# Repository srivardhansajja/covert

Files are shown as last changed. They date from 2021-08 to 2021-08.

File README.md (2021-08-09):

# Covert Communications Device

## UIUC ECE 445 Senior Design / Capstone Project

Won Best Engineered Project Award, and permanently listed in the [Hall of Fame](https://courses.engr.illinois.edu/ece445/hall-of-fame.asp) for Spring 2021

## Abstract

The primary purpose of this project is to provide a means for safe and effective communication in highly sensitive military and law-enforcement operations.

It is important for a two-way channel of communication to exist between the base and individuals in the field. Regular communication tools have output which can disrupt sensory awareness of the user thereby rendering them unsuitable for information transmission in these situations. A wearable device thatrelays messages that are only detectable by the user, and that will not affect their focus is the purpose of this project.

The final output of this project is a small device that can be installed on the human body in a convenient location, such as the upper arm or the outer thigh. The user should be able to access the device using their hand. The device will transmit information to the user through the cadence of haptic feedback (vibration patterns). The user will also be able to transmit information to all other devices in near real-time using a button on the device (pressing the button with whatever cadence is required, e.g. long-short-short). Team selected codes can be established to effectively transmit complex information or instructions.

## Prototype

Prototypes

## Block Diagram

Block Diagram

## Documents
- [Project Report](https://courses.engr.illinois.edu/ece445/getfile.asp?id=19398)
- [Design Document](https://courses.engr.illinois.edu/ece445/getfile.asp?id=19192)
- [Proposal](https://courses.engr.illinois.edu/ece445/getfile.asp?id=18686)

## Software
- STM32 CubeIDE development, LoRa radio communications + crypto libraries

## Board
- Eagle schematic + board files 
- CAD casing layout
- Gerber files

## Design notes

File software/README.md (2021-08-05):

# Sources:
https://github.com/henriheimann/stm32-hal-rfm95

https://github.com/sandeepmistry/arduino-LoRa

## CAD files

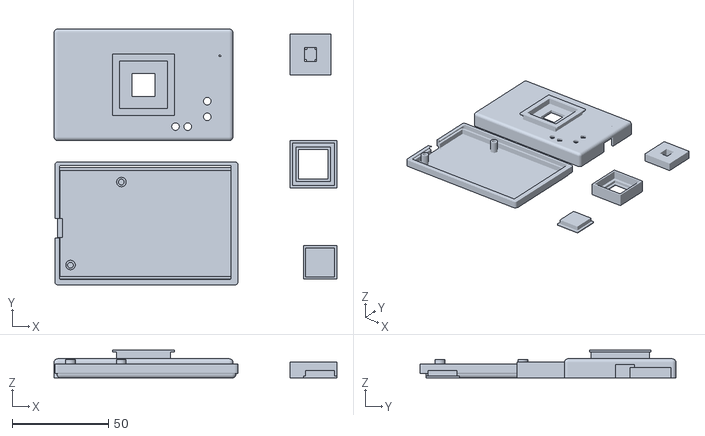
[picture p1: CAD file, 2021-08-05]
board/tinker.obj
147.0 x 133.0 x 14.5

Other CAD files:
board/seniordesign.dwg

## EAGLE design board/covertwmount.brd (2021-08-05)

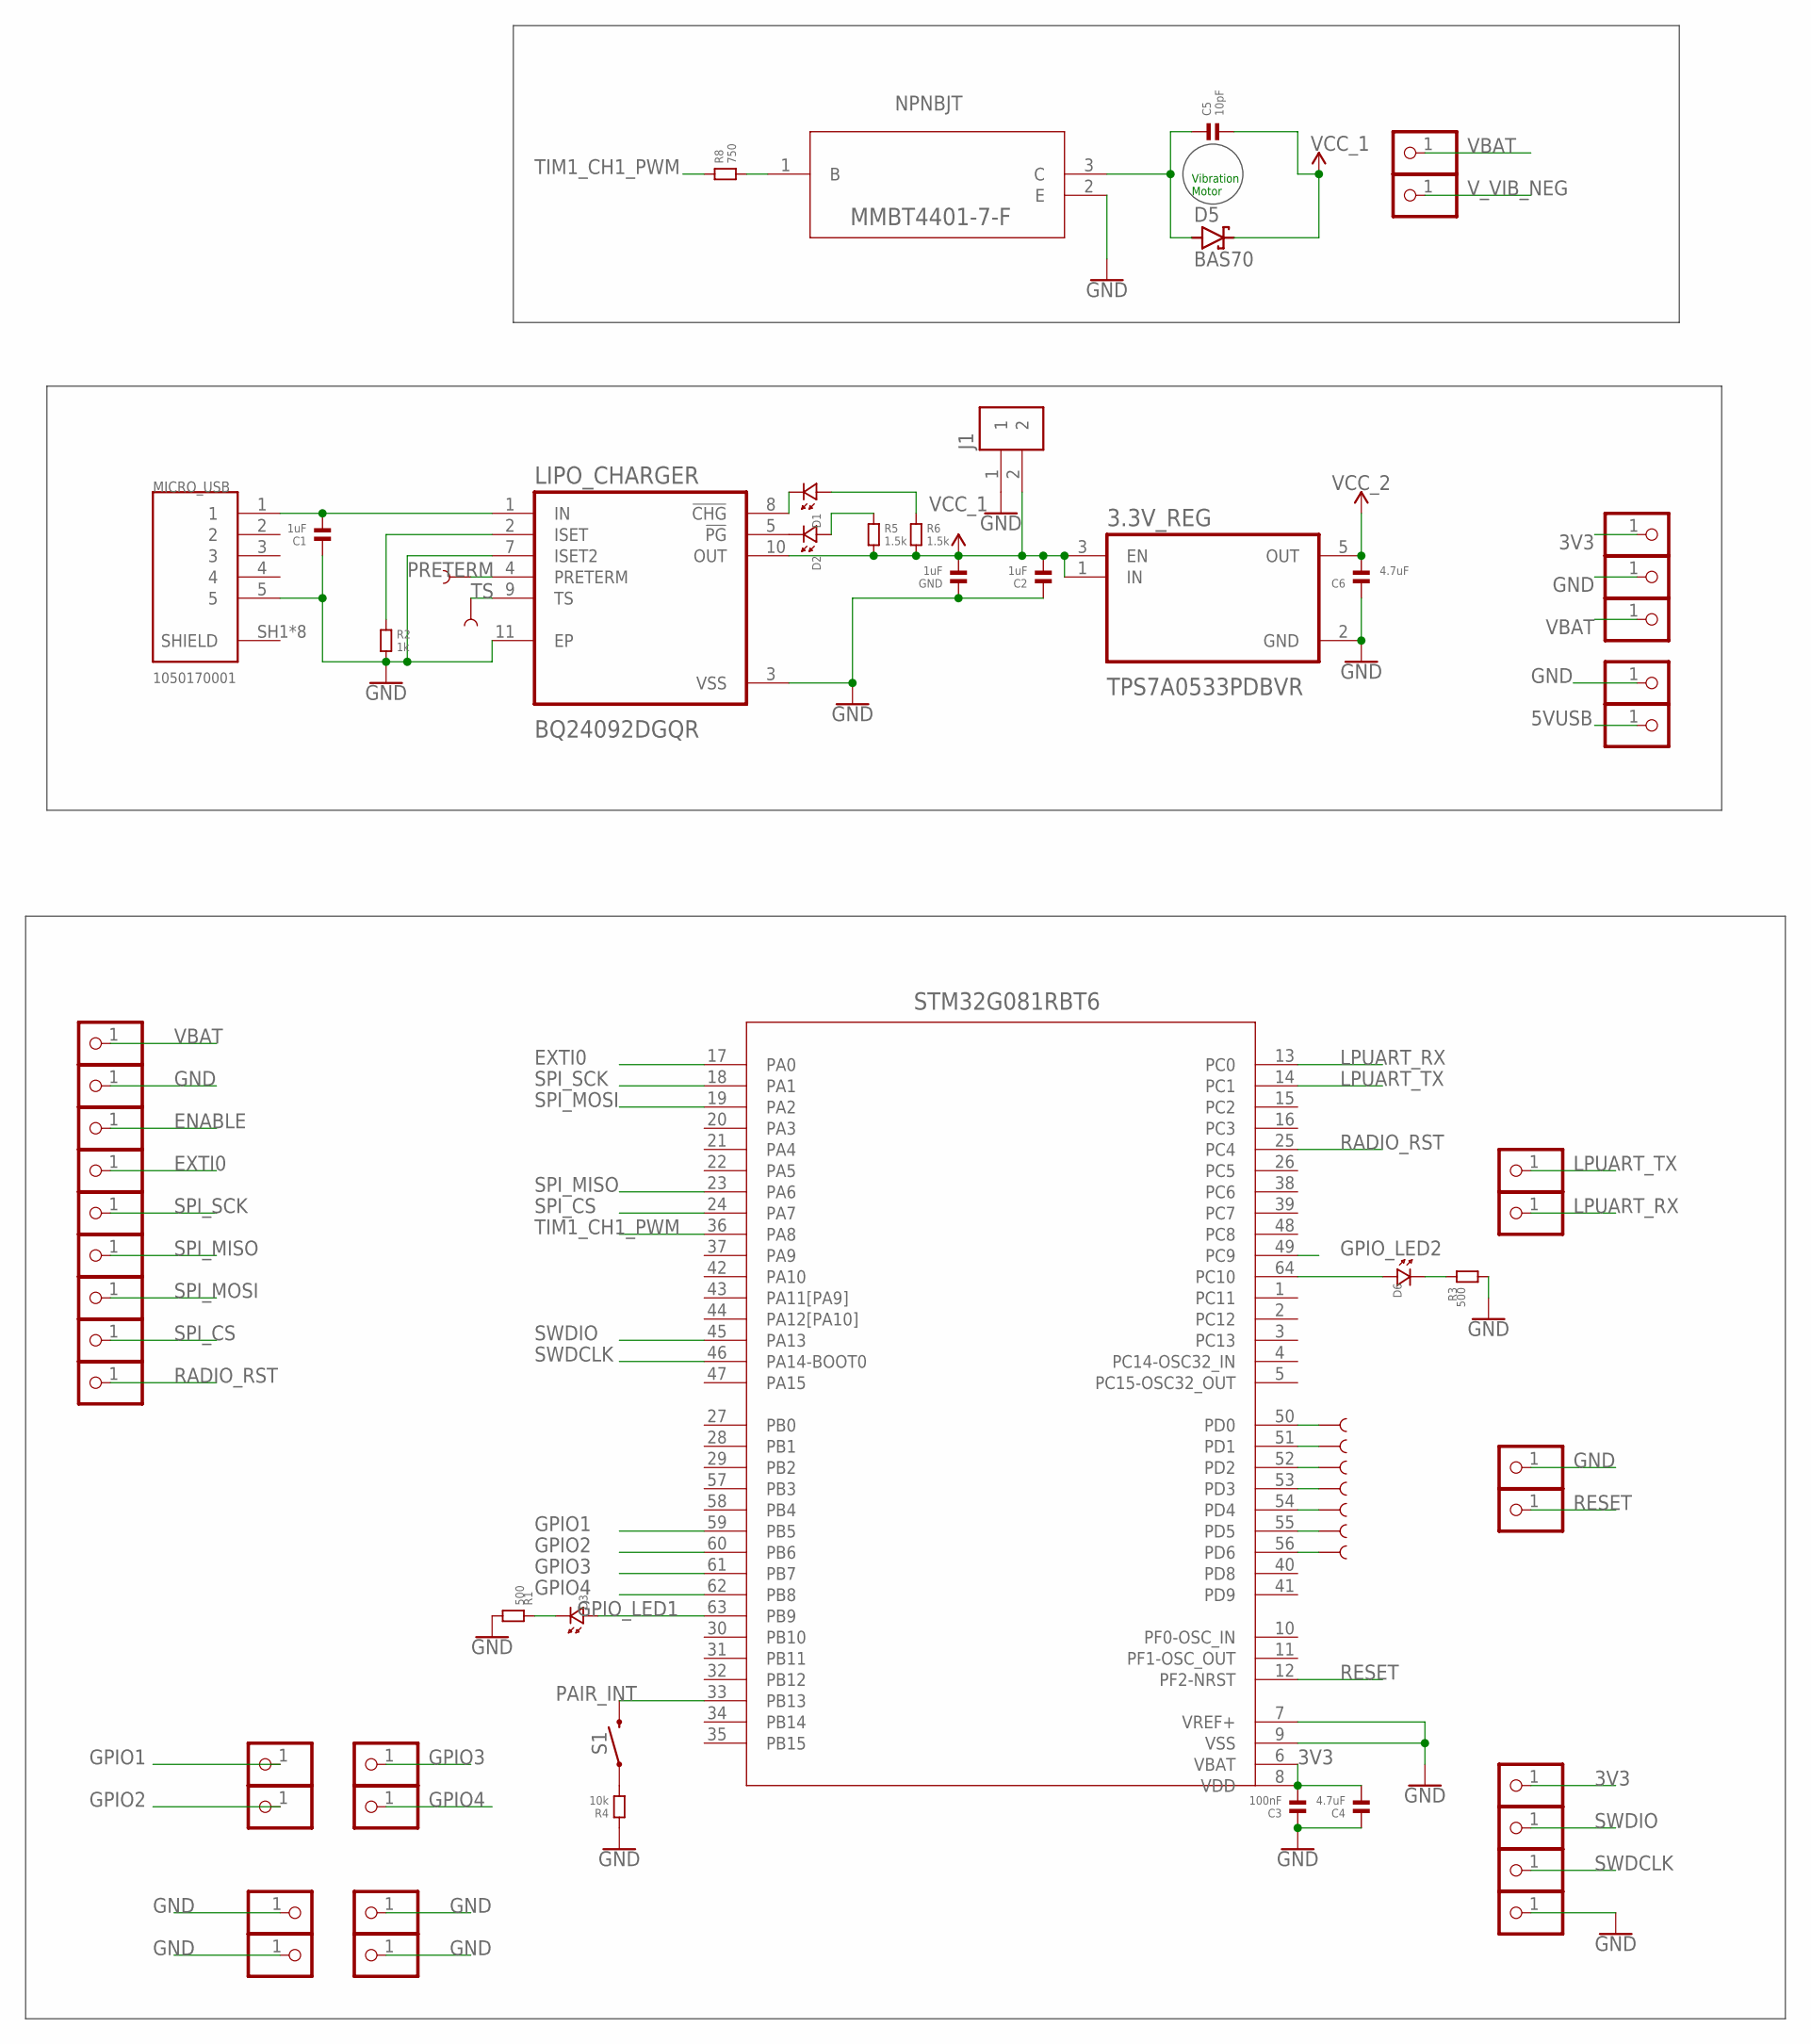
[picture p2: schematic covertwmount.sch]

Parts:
3.3V_REG: TPS7A0533PDBVR; SOT95P280X145-5N
C1, C2: 1uF; 0805
C3: 100nF; 0805
C4, C6: 4.7uF; 0805
C5: 10pF; 0805
D1, D2, D3, D6: LED.0805; 0805.LED
D5: BAS70; SOT23
GND: 1uF; 0805
J1: B2B-PH-K-S(LF)(SN); JST_B2B-PH-K-S(LF)(SN)
JP1, JP2, JP3, JP4, JP5, JP6, JP7, JP8, JP9, JP10, JP11, JP12, JP13, JP14, JP15, JP16, JP17, JP18, JP19, JP20, JP21, JP22, JP23, JP24, JP26, JP27, JP28, JP29, JP30, JP31, JP32, JP33: PINHD-1X1; 1X01
LIPO_CHARGER: BQ24092DGQR; IC_XTR111AIDGQR
MICRO_USB: 1050170001; MOLEX_1050170001
R1, R3: 500; 0805
R2: 1k; 0805
R4: 10k; 0805
R5, R6: 1.5k; 0805
R8: 750; 0805
S1: MOMENTARY-SWITCH-SPST-PTH-6.0MM; TACTILE_SWITCH_PTH_6.0MM
TP1, TP2, TP3, TP4, TP5, TP6, TP7, TP8, TP9: TEST-POINT2; PAD.02X.02
U1: STM32G081RBT6; LQFP-64
U2: MMBT4401-7-F; SOT-23_DIO

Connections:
3V3: 3.3V_REG.5 (OUT), C3.2, C4.2, C6.2, JP4.1, JP16.1, U1.6 (VBAT), U1.8 (VDD)
5VUSB: C1.2, JP30.1, LIPO_CHARGER.1 (IN), MICRO_USB.1
ENABLE: JP11.1
EXTI0: JP10.1, U1.17 (PA0)
GND: 3.3V_REG.2 (GND), C1.1, C2.1, C3.1, C4.1, C6.1, GND.1, J1.1, JP3.1, JP12.1, JP15.1, JP23.1, JP26.1, JP27.1, JP28.1, JP29.1, JP33.1, LIPO_CHARGER.3 (VSS), LIPO_CHARGER.7 (ISET2), LIPO_CHARGER.11 (EP), MICRO_USB.5, R1.1, R2.2, R3.1, R4.1, U1.7 (VREF+), U1.9 (VSS), U2.2 (E)
GPIO1: JP19.1, U1.59 (PB5)
GPIO2: JP20.1, U1.60 (PB6)
GPIO3: JP17.1, U1.61 (PB7)
GPIO4: JP18.1, U1.62 (PB8)
GPIO_LED1: D3.P$1 (1), U1.63 (PB9)
GPIO_LED2: D6.P$1 (1), U1.64 (PC10)
LPUART_RX: JP32.1, U1.13 (PC0)
LPUART_TX: JP31.1, U1.14 (PC1)
unnamed: LIPO_CHARGER.2 (ISET), R2.1
unnamed: D6.P$2 (2), R3.2
unnamed: D3.P$2 (2), R1.2
unnamed: D2.P$1 (1), R5.1
unnamed: D1.P$1 (1), R6.1
unnamed: D2.P$2 (2), LIPO_CHARGER.5 (!PG)
unnamed: R8.2, U2.1 (B)
unnamed: R4.2, S1.1
unnamed: D1.P$2 (2), LIPO_CHARGER.8 (!CHG)
PAIR_INT: S1.3 (2), U1.33 (PB13)
PD0: TP3.P$1, U1.50 (PD0)
PD1: TP4.P$1, U1.51 (PD1)
PD2: TP5.P$1, U1.52 (PD2)
PD3: TP6.P$1, U1.53 (PD3)
PD4: TP7.P$1, U1.54 (PD4)
PD5: TP8.P$1, U1.55 (PD5)
PD6: TP9.P$1, U1.56 (PD6)
PRETERM: LIPO_CHARGER.4 (PRETERM), TP2.P$1
RADIO_RST: JP5.1, U1.25 (PC4)
RESET: JP24.1, U1.12 (PF2-NRST)
SPI_CS: JP6.1, U1.24 (PA7)
SPI_MISO: JP8.1, U1.23 (PA6)
SPI_MOSI: JP7.1, U1.19 (PA2)
SPI_SCK: JP9.1, U1.18 (PA1)
SWDCLK: JP2.1, U1.46 (PA14-BOOT0)
SWDIO: JP1.1, U1.45 (PA13)
TIM1_CH1_PWM: R8.1, U1.36 (PA8)
TS: LIPO_CHARGER.9 (TS), TP1.P$1
VBAT: 3.3V_REG.1 (IN), 3.3V_REG.3 (EN), C2.2, C5.2, D5.3 (C), GND.2, J1.2, JP13.1, JP14.1, JP21.1, LIPO_CHARGER.10 (OUT), R5.2, R6.2
V_VIB_NEG: C5.1, D5.1 (A), JP22.1, U2.3 (C)

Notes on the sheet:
Vibration Motor

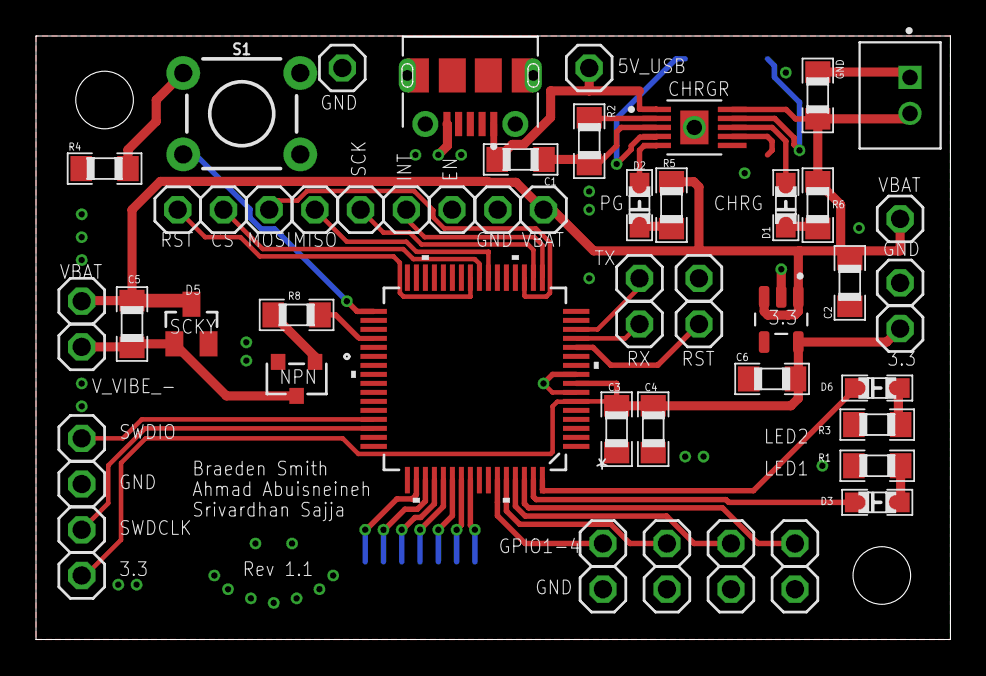
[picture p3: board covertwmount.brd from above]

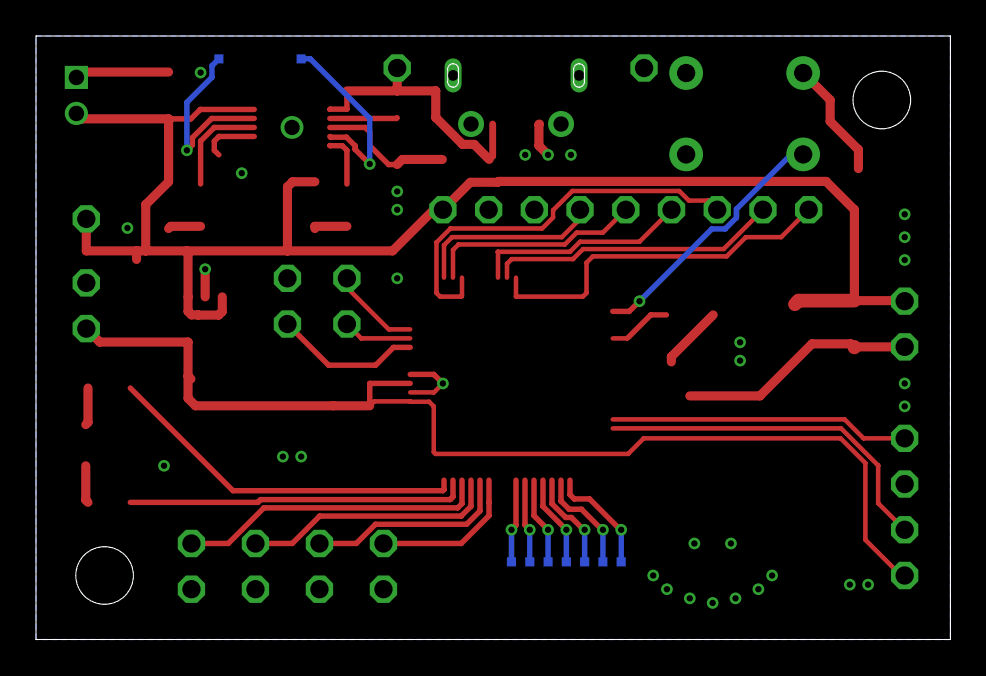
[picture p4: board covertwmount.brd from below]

Board: 2 copper layers, 50.8 x 33.5 mm, 67 parts (9 on the bottom side), 42 nets.

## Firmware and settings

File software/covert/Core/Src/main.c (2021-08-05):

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
/* Includes ------------------------------------------------------------------*/
#include "main.h"

/* USER CODE BEGIN Includes */
#include <string.h>
#include <assert.h>
#include "crypto.h"
#include "rfm95.h"

/* USER CODE END Includes */

/* USER CODE BEGIN PTD */
typedef struct {
	uint32_t privateKey[8];
	uint8_t publicKey[32];
	uint8_t otherPublicKey[32];
	uint8_t sharedSecret[32];
	volatile uint8_t gotOther;
	volatile uint8_t masterSent;
	volatile uint8_t pairing;
} AsymmetricKeys;

typedef struct {
	volatile uint8_t enabled;
	uint8_t count;
	uint64_t data;
} Record;

typedef struct __attribute__((__packed__)) {
	uint8_t preamble;
	uint8_t deviceID;
	uint32_t sequenceNumber;
	uint64_t data;
	uint16_t _placeholder;
} Packet;

typedef struct __attribute__((__packed__)) {
	uint8_t preamble;
	uint8_t data[32];
} PublicKeyPacket;

typedef struct __attribute__((__packed__)) {
	uint8_t preamble;
	uint8_t data[16];
} KeyExchangePacket;

/* USER CODE END PTD */

/* USER CODE BEGIN PD */

#define MASTER_DEVICE 	0
#define DEVICE_ID 		1
#define RESET 			0
#define NEW_SEQ			0

#define AESKeySize 128/8 //(8 * sizeof(uint32_t));
#define PUBLIC_EXCHANGE_PREAMBLE 0b01010101
#define AES_KEY_EXCHANGE_PREAMBLE 0b10101010
#define VIBE_PREAMBLE 0b11110000
#define DUTY_CYCLE_ON 10
/* USER CODE END PD */

CRYP_HandleTypeDef hcryp;
uint32_t pKeyAES[4] __ALIGN_END = { 0x00000000,
		0x00000000, 0x00000000, 0x00000000 };
__ALIGN_BEGIN static const uint32_t pInitVectAES[4] __ALIGN_END = { 0x5B841799,
		0xF2DBC132, 0x3961879F, 0x8B3F49C0 };

CRC_HandleTypeDef hcrc;

RNG_HandleTypeDef hrng;

SPI_HandleTypeDef hspi1;

TIM_HandleTypeDef htim1;
TIM_HandleTypeDef htim16;

/* USER CODE BEGIN PV */
FLASH_EraseInitTypeDef EraseInitStruct;
FLASH_EraseInitTypeDef EraseSeqStruct;

AsymmetricKeys aKeys;
Record playback;
Record recording;
Packet outgoing;
rfm95_handle_t radio;
uint32_t deviceSeqs[256] = { 0 };

/* USER CODE END PV */

void SystemClock_Config(void);
static void MX_GPIO_Init(void);
static void MX_AES_Init(void);
static void MX_RNG_Init(void);
static void MX_CRC_Init(void);
static void MX_TIM16_Init(void);
static void MX_TIM1_Init(void);
static void MX_SPI1_Init(void);
/* USER CODE BEGIN PFP */
static void readKeyFromFlash(uint32_t *ptr, FLASH_EraseInitTypeDef *erase);
static void writeKeyToFlash(uint64_t *ptr, FLASH_EraseInitTypeDef *erase);
static uint32_t readSeqFromFlash(FLASH_EraseInitTypeDef *erase);
static void writeSeqToFlash(uint32_t seq, FLASH_EraseInitTypeDef *erase);
static void readingCallback(uint8_t *buffer, uint8_t length);
/* USER CODE END PFP */

/**
 * @brief  The application entry point.
 * @retval int
 */
int main(void) {
	/* MCU Configuration--------------------------------------------------------*/

	/* Reset of all peripherals, Initializes the Flash interface and the Systick. */
	HAL_Init();

	/* Configure the system clock */
	SystemClock_Config();

	/* USER CODE BEGIN SysInit */
	uint8_t testing = sizeof(Packet);
	assert(
			sizeof(PublicKeyPacket) == 33 && sizeof(KeyExchangePacket) == 17
					&& sizeof(Packet) == 16);
	// Key writing to flash
	EraseInitStruct.Banks = FLASH_BANK_1;
	EraseInitStruct.TypeErase = FLASH_TYPEERASE_PAGES;
	EraseInitStruct.Page = (FLASH_PAGE_NB - 1);
	EraseInitStruct.NbPages = 1;

	// Sequence Number storing in flash
	EraseSeqStruct.Banks = FLASH_BANK_1;
	EraseSeqStruct.TypeErase = FLASH_TYPEERASE_PAGES;
	EraseSeqStruct.Page = (FLASH_PAGE_NB - 2);
	EraseSeqStruct.NbPages = 1;

	recording.enabled = 0;
	playback.enabled = 0;

	radio.spi_handle = &hspi1;

	radio.nss_port = RADIO_CS_GPIO_Port;
	radio.nss_pin = RADIO_CS_Pin;
	radio.nrst_port = RADIO_RESET_GPIO_Port;
	radio.nrst_pin = RADIO_RESET_Pin;
	radio.irq_port = RADIO_INT_GPIO_Port;
	radio.irq_pin = RADIO_INT_Pin;

	radio.txDone = true;
	radio.rxDoneCallback = readingCallback;

	aKeys.gotOther = 0;
	aKeys.pairing = 0;
	aKeys.masterSent = 0;
	aKeys.sharedSecret[0] = 0;

	outgoing.data = 0;

	/* USER CODE END SysInit */

	/* Initialize all configured peripherals */
	MX_GPIO_Init();
	MX_AES_Init();
	MX_RNG_Init();
	MX_CRC_Init();
	MX_TIM16_Init();
	MX_TIM1_Init();
	MX_SPI1_Init();
	/* USER CODE BEGIN 2 */

	HAL_Delay(100);
	if (!rfm95_init(&radio)) {
		HAL_GPIO_WritePin(LED2_GPIO_Port, LED2_Pin, GPIO_PIN_SET);
		HAL_GPIO_WritePin(LED1_GPIO_Port, LED1_Pin, GPIO_PIN_SET);

		while (1) {

		}
	}

	HAL_TIM_Base_Start_IT(&htim16);
	HAL_TIM_PWM_Start(&htim1, TIM_CHANNEL_1);

	readKeyFromFlash(pKeyAES, &EraseInitStruct);
	// We lost our random key or we want a reset?
	if (RESET || pKeyAES[0] == 0 || pKeyAES[0] == UINT32_MAX) {
		uint64_t tmp[2];
		for (int i = 0; i < 2; i++) {
			if (HAL_RNG_GenerateRandomNumber(&hrng, &tmp[i]) != HAL_OK)
				Error_Handler();
			tmp[i] <<= 32;
			if (HAL_RNG_GenerateRandomNumber(&hrng, &tmp[i]) != HAL_OK)
				Error_Handler();
		}
		writeKeyToFlash(tmp, &EraseInitStruct);
		readKeyFromFlash(pKeyAES, &EraseInitStruct);
	}
	MX_AES_Init();

	// Generate a random sequence number for packets -- assume 2000 is the most packets we'll ever send while devices haven't rebooted
	deviceSeqs[DEVICE_ID] = readSeqFromFlash(&EraseSeqStruct);
	if (NEW_SEQ || deviceSeqs[DEVICE_ID] >= ((UINT32_MAX) >> 1)
			|| deviceSeqs[DEVICE_ID] == 0) {
		uint32_t seq = 0;
		HAL_RNG_GenerateRandomNumber(&hrng, &seq);
		seq >>= 1;
		deviceSeqs[DEVICE_ID] = seq;
	}
	deviceSeqs[DEVICE_ID] += 2000;
	writeSeqToFlash(deviceSeqs[DEVICE_ID], &EraseSeqStruct);

	// Might as well generate a public key in advance
	for (int i = 0; i < 8; i++) {
		HAL_RNG_GenerateRandomNumber(&hrng, &aKeys.privateKey[i]);
	}
	C25519keyGen((uint8_t*) aKeys.privateKey, aKeys.publicKey);

	/* USER CODE END 2 */

	/* Infinite loop */
	/* USER CODE BEGIN WHILE */
	while (1) {
		if (aKeys.pairing && aKeys.pairing++ <= 5) {
			// send our public key in plaintext.
			PublicKeyPacket tmp;
			tmp.preamble = PUBLIC_EXCHANGE_PREAMBLE;
			memcpy(tmp.data, aKeys.publicKey, sizeof(tmp.data));
			transmitPackage(&tmp, sizeof(PublicKeyPacket));
			// randomize the delay here
			uint32_t randoffset = 0;
			HAL_RNG_GenerateRandomNumber(&hrng, &randoffset);

			HAL_Delay(1000 + (randoffset & 0x7ff));
			continue;
		} else {
			aKeys.pairing = 0;
		}

		if (aKeys.gotOther) {
			C25519keyExchange(aKeys.sharedSecret, (uint8_t*) aKeys.privateKey,
					aKeys.otherPublicKey);
//			rfm95_init(&radio);
			aKeys.gotOther = 0;
			aKeys.masterSent = 1;
		}

		if (aKeys.masterSent && aKeys.masterSent++ <= 10) {
			if (MASTER_DEVICE) {
				// Save the "master's secret key" in old pkeys
				uint32_t oldPkeys[4] = { 0 };
				memcpy(oldPkeys, pKeyAES, AESKeySize);
				// move the shared secret to the AES hardware for encryption
				memcpy(pKeyAES, aKeys.sharedSecret, AESKeySize);
				MX_AES_Init();
				// Create a packet & attack the "master's key"
				KeyExchangePacket tmp;
				tmp.preamble = AES_KEY_EXCHANGE_PREAMBLE;
				memcpy(tmp.data, oldPkeys, AESKeySize);

				// Output the encrypted packet in a buffer
				uint8_t inputBuf[32] = { 0 };
				memcpy(inputBuf, &tmp, sizeof(KeyExchangePacket));
				uint8_t outputBuf[32] = { 0 };

				if (HAL_CRYP_Encrypt(&hcryp, inputBuf, 32, outputBuf, 1)
						== HAL_OK) {
					transmitPackage(outputBuf, 32);
				}
				memcpy(pKeyAES, oldPkeys, AESKeySize);
				MX_AES_Init();
			} else {
				//we're a slave device and we can just sit and wait for master count to ++
			}
			HAL_GPIO_WritePin(LED1_GPIO_Port, LED1_Pin, GPIO_PIN_RESET);
			HAL_GPIO_WritePin(LED2_GPIO_Port, LED2_Pin, GPIO_PIN_SET);
			HAL_Delay(500);
			HAL_GPIO_WritePin(LED1_GPIO_Port, LED1_Pin, GPIO_PIN_SET);
			HAL_GPIO_WritePin(LED2_GPIO_Port, LED2_Pin, GPIO_PIN_RESET);
			HAL_Delay(500);
			continue;
		} else {
			aKeys.masterSent = 0;
		}

		if (outgoing.data) {
			//encrypt and transmit the outgoing packet
			uint32_t tempin[4] = { 0 };
			uint32_t tempout[4] = { 0 };
			memcpy(tempin, &outgoing, sizeof(Packet));
			HAL_CRYP_Encrypt(&hcryp, (uint8_t*) tempin, 16, (uint8_t*) tempout,
					1);
			outgoing.data = 0;
			for (uint8_t i = 0; i < 3; i++) {
				while (!transmitPackage((uint8_t*) tempout, 16)) {
					HAL_Delay(70);
				}
			}
			continue;
		}

		HAL_GPIO_TogglePin(LED1_GPIO_Port, LED1_Pin);

//		HAL_GPIO_TogglePin(GPIOB, GPIO_PIN_9);
		HAL_Delay(250);
		/* USER CODE END WHILE */

		/* USER CODE BEGIN 3 */
	}
	/* USER CODE END 3 */
}

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
/* USER CODE BEGIN 4 */

void HAL_GPIO_EXTI_Falling_Callback(uint16_t GPIO_Pin) {
//	To enable instant replay
//	if (GPIO_Pin == VIBE_BUTTON_Pin) {
//		TIM1->CCR1 = (DUTY_CYCLE_ON * UINT16_MAX) / 10;
//		HAL_GPIO_WritePin(LED2_GPIO_Port, LED2_Pin, GPIO_PIN_SET);
//	}

	if (recording.enabled || aKeys.pairing) {
		return;
	}
	if (GPIO_Pin == PAIR_Pin) {
		// in actual pairing
		aKeys.pairing = 1;

	} else if (GPIO_Pin == VIBE_BUTTON_Pin) {
		// on vibe button:
		recording.enabled = 1;
		recording.count = 1;
		recording.data = 1;
	}
}

void HAL_GPIO_EXTI_Rising_Callback(uint16_t GPIO_Pin) {
	if (GPIO_Pin == RADIO_INT_Pin) {
		rfm95_handleInterrupt();
	}
//	To enable instant replay
//	if (GPIO_Pin == VIBE_BUTTON_Pin) {
//		TIM1->CCR1 = 0;
//		HAL_GPIO_WritePin(LED2_GPIO_Port, LED2_Pin, GPIO_PIN_RESET);
//	}
}

void HAL_TIM_PeriodElapsedCallback(TIM_HandleTypeDef *htim) {
	if (aKeys.pairing) {
		HAL_GPIO_TogglePin(LED2_GPIO_Port, LED2_Pin);
	}
//	if (aKeys.masterSent) {
//		HAL_GPIO_TogglePin(LED1_GPIO_Port, LED1_Pin);
//	}

	if (htim == &htim16 && (recording.enabled || playback.enabled)) {

		if (playback.enabled) {
			uint64_t shifted = (playback.data >> (playback.count++));
			uint8_t state = shifted & 1;

			TIM1->CCR1 = state ? (DUTY_CYCLE_ON * UINT16_MAX) / 10 : 0;
			HAL_GPIO_WritePin(LED2_GPIO_Port, LED2_Pin,
					(state ? GPIO_PIN_SET : GPIO_PIN_RESET));

			if (playback.count >= sizeof(playback.data) * 8) {
				playback.enabled = 0;
				HAL_GPIO_WritePin(LED2_GPIO_Port, LED2_Pin, GPIO_PIN_RESET);
				TIM1->CCR1 = 0;
			}
		}

		if (recording.enabled) {
			uint64_t read = (
					HAL_GPIO_ReadPin(VIBE_BUTTON_GPIO_Port, VIBE_BUTTON_Pin)
							== GPIO_PIN_RESET ? 1 : 0);
			uint64_t state = read << (recording.count++);
			recording.data |= state;
			if (recording.count >= sizeof(recording.data) * 8) {
				// packet should be formed & sent here

				outgoing.deviceID = DEVICE_ID;
				outgoing.preamble = VIBE_PREAMBLE;
				outgoing.sequenceNumber = ++deviceSeqs[DEVICE_ID];
				outgoing.data = recording.data;

				// replay on local device:
//				playback.data = recording.data;
//				playback.enabled = 1;
//				playback.count = 0;

				recording.enabled = 0;
				if (state) {
					recording.enabled = 1;
					recording.count = 1;
					recording.data = 1;
				}

			}
		}
	}
}

static void readingCallback(uint8_t *buffer, uint8_t length) {
	if (aKeys.pairing && length == sizeof(PublicKeyPacket)) {
		PublicKeyPacket tmp;
		tmp.preamble = 0;
		memcpy(&tmp, buffer, length);
		if (tmp.preamble == PUBLIC_EXCHANGE_PREAMBLE) {
			memcpy(aKeys.otherPublicKey, tmp.data, 32);
			aKeys.gotOther = 1;
		}
	} else if (!MASTER_DEVICE && length == 32 && aKeys.masterSent) {
		// try to decrypt with shared secret
		uint32_t oldPkeys[4] = { 0 };

		memcpy(oldPkeys, pKeyAES, AESKeySize);
		memcpy(pKeyAES, aKeys.sharedSecret, AESKeySize);
		MX_AES_Init();

		uint8_t decryptRes[32] = { 0 };
		if (HAL_CRYP_Decrypt(&hcryp, buffer, length, decryptRes, 1) == HAL_OK) {
			KeyExchangePacket tmp;
			tmp.preamble = 0;
			memcpy(&tmp, decryptRes, sizeof(decryptRes));
			if (tmp.preamble == AES_KEY_EXCHANGE_PREAMBLE) {
				writeKeyToFlash((uint64_t*) tmp.data, &EraseInitStruct);

				memcpy(pKeyAES, tmp.data, AESKeySize);
				// We don't necessarily have to have this here -- we can let it keep writing
				aKeys.masterSent = 0;
			}
		} else {
			memcpy(pKeyAES, oldPkeys, AESKeySize);
		}
		MX_AES_Init();
	} else if (length == sizeof(Packet)) {
		Packet tmp;
		tmp.preamble = 0;
		if (HAL_CRYP_Decrypt(&hcryp, buffer, length, &tmp, 1) == HAL_OK
				&& tmp.preamble == VIBE_PREAMBLE
				&& tmp.sequenceNumber > deviceSeqs[tmp.deviceID]) {

			playback.data = tmp.data;
			playback.enabled = 1;
			playback.count = 0;
			deviceSeqs[tmp.deviceID] = tmp.sequenceNumber;

		}
	}
}

static void readKeyFromFlash(uint32_t *ptr, FLASH_EraseInitTypeDef *erase) {

	uint32_t addr = 0x08000000 + FLASH_PAGE_SIZE * erase->Page;
	for (int i = 0; i < AESKeySize / sizeof(uint32_t); i++) {
		ptr[i] = ((uint32_t*) addr)[i];
	}
}

static void writeKeyToFlash(uint64_t *ptr, FLASH_EraseInitTypeDef *erase) {
//801f800
	uint32_t addr = 0x08000000 + FLASH_PAGE_SIZE * erase->Page;

	uint32_t pgerr = 0;
	HAL_FLASH_Unlock();
	HAL_FLASHEx_Erase(erase, &pgerr);
	uint64_t alignedtmp[2] = { 0 };
	memcpy(alignedtmp, ptr, sizeof(alignedtmp));
	for (int i = 0; i < 2; i++) {
		uint64_t val = alignedtmp[i];
		uint32_t location = addr + (sizeof(uint64_t)) * i;
		HAL_FLASH_Program(FLASH_TYPEPROGRAM_DOUBLEWORD, location, val);
	}
	HAL_FLASH_Lock();
}

static uint32_t readSeqFromFlash(FLASH_EraseInitTypeDef *erase) {
	uint32_t addr = 0x08000000 + FLASH_PAGE_SIZE * erase->Page;
	return *((uint32_t*) addr);
}
static void writeSeqToFlash(uint32_t seq, FLASH_EraseInitTypeDef *erase) {
//801f000
	uint32_t addr = 0x08000000 + FLASH_PAGE_SIZE * erase->Page;
	uint32_t pgerr = 0;
	HAL_FLASH_Unlock();
	HAL_FLASHEx_Erase(erase, &pgerr);
	HAL_FLASH_Program(FLASH_TYPEPROGRAM_DOUBLEWORD, addr, seq);
	HAL_FLASH_Lock();
}

/* USER CODE END 4 */
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


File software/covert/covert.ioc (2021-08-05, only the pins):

Mcu.UserName=STM32G081RBTx
PA0.GPIO_Label=RADIO_INT
PA0.Signal=GPXTI0
PA1.Signal=SPI1_SCK
PA13.Signal=SYS_SWDIO
PA14-BOOT0.Signal=SYS_SWCLK
PA2.Signal=SPI1_MOSI
PA6.Signal=SPI1_MISO
PA7.GPIO_Label=RADIO_CS
PA7.Signal=GPIO_Output
PA8.GPIO_Label=VIBE_PWM
PA8.Signal=S_TIM1_CH1
PB13.GPIO_Label=PAIR
PB13.Signal=GPXTI13
PB8.GPIO_Label=VIBE_BUTTON
PB8.Signal=GPXTI8
PB9.GPIO_Label=LED1
PB9.Signal=GPIO_Output
PC10.GPIO_Label=LED2
PC10.Signal=GPIO_Output
PC4.GPIO_Label=RADIO_RESET
PC4.Signal=GPIO_Output

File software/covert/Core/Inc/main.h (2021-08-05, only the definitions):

#define RADIO_INT_Pin GPIO_PIN_0
#define RADIO_INT_GPIO_Port GPIOA
#define RADIO_INT_EXTI_IRQn EXTI0_1_IRQn
#define RADIO_CS_Pin GPIO_PIN_7
#define RADIO_CS_GPIO_Port GPIOA
#define RADIO_RESET_Pin GPIO_PIN_4
#define RADIO_RESET_GPIO_Port GPIOC
#define PAIR_Pin GPIO_PIN_13
#define PAIR_GPIO_Port GPIOB
#define PAIR_EXTI_IRQn EXTI4_15_IRQn
#define VIBE_PWM_Pin GPIO_PIN_8
#define VIBE_PWM_GPIO_Port GPIOA
#define VIBE_BUTTON_Pin GPIO_PIN_8
#define VIBE_BUTTON_GPIO_Port GPIOB
#define VIBE_BUTTON_EXTI_IRQn EXTI4_15_IRQn
#define LED1_Pin GPIO_PIN_9
#define LED1_GPIO_Port GPIOB
#define LED2_Pin GPIO_PIN_10
#define LED2_GPIO_Port GPIOC

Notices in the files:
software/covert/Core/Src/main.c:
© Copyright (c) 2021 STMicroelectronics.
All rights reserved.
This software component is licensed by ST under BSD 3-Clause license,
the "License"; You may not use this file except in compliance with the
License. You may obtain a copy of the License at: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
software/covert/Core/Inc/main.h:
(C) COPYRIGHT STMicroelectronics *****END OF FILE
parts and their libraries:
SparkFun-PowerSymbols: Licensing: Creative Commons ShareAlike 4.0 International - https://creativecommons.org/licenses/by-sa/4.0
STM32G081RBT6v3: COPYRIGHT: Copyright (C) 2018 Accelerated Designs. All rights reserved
